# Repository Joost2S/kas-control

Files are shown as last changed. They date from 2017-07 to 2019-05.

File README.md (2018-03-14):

# kas-control
Kas Control is a Raspberry Pi expansion board for watering plants and checking a few more environmental variables
PCB should be correct.
Software is currently not functional. Use v2017 for basic functionality.

Features
--------
- PCB plugs straight into your rPi. rPi is powered through the PCB
- Measuring soil moisture level of up to 7 plants/containers
  - Can pump water to plant/container when moisture level is below threshold so you don't have to!
- Measuring amount of water given per channel and total
- Default 3 temperature sensors are supported by the board. Software supports infinite sensors. Make a simple breakout (connect parallel) board for more sensors.
- Light sensor for ambient light measurement.
- Float switch for use in a water container.
- Outputs:
  - 2 configurable LEDbars.
  - Standard HD44780 16x2 or 20x4 character LCD with driver kindly copied from ADAfruit.
- Network client to set the various setting and get the data.
  - Command-line only. Graph makes a Google graph html file that will open in a new tab in your browser
  - Basic encryption is implemented with openSSL
- Database
  - All sensor data is logged
  - Add a name and plant type to keep track of which plants you've grown
- 5v/12v 4A PSU PCB with INA219 power monitor. PCB files are available, haven't tested it yet.
  - 4 powerLED connectors are available for 350/500/700mA powerLED strips.
  - Power monitoring is available via INA219 ICs
  
Future Features
---------------
- Network
  - Full-fledged GUI for the network client. Probably built on Kivy.
  - rPi camera support so you can watch your plants from all over the world
- Database
  - Adding results such as plant size or harvest amount to each of your plants. Manual input only of course.
- Implement event system

Motivation
----------

I like weed. I like electronics. I like programming. Here's the result :)

Installation/requirements
-------------------------

- I use Arch Linux so only instructions for that. Actual instructions will follow later.
- RPi.GPIO
- SMBus for i2c
- spidev for SPI
- SQlite for database
- Kivy (future)

Contributors
------------

Sorry, no help wanted. This is my pet project and I want it to be just how I like it. Of Course you are welcome to use the code and pcb files as you wish.

License
-------

GNU General Public License v3.0

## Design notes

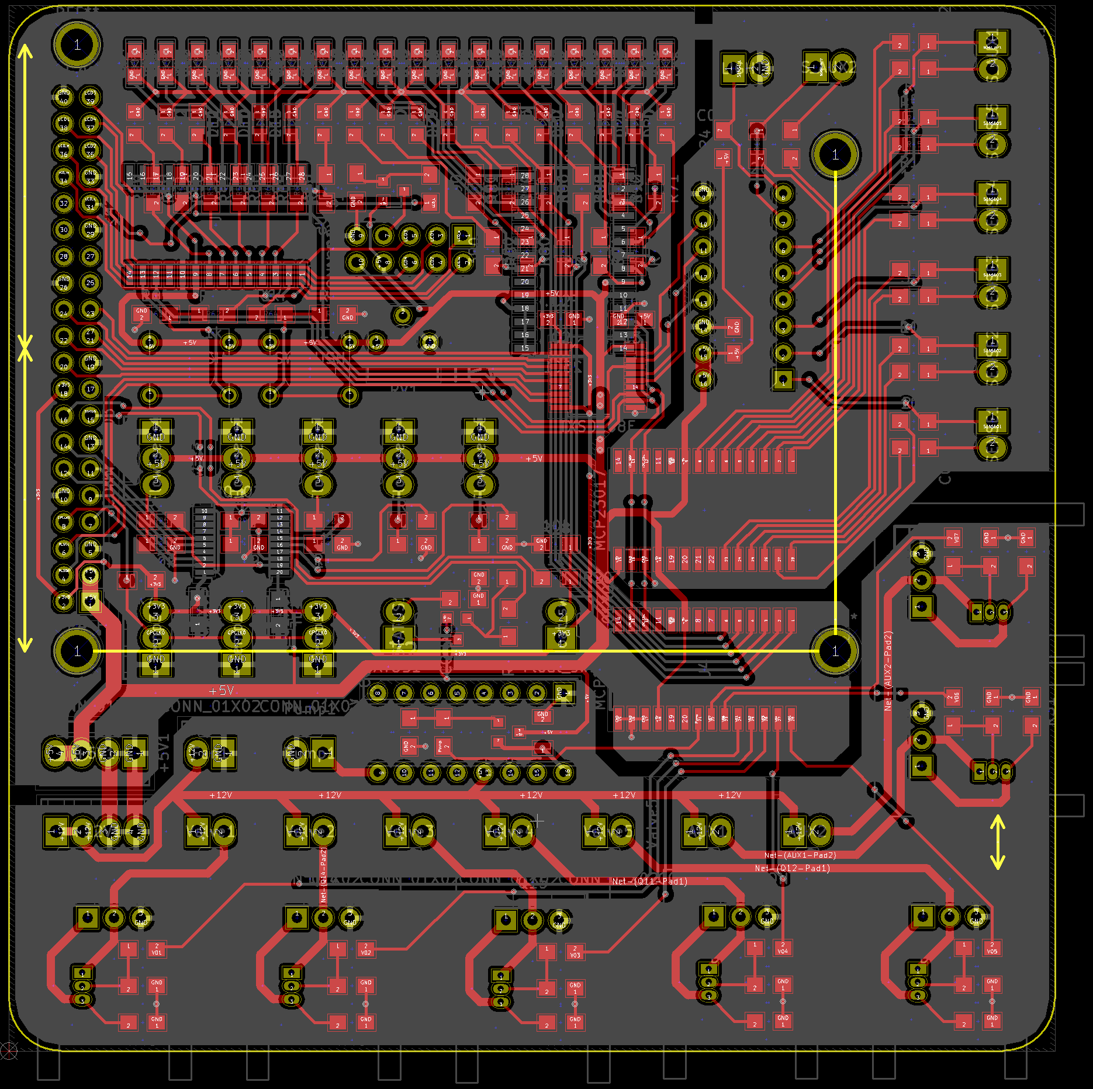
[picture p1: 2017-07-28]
PCB/MainBoard/f.cu.png

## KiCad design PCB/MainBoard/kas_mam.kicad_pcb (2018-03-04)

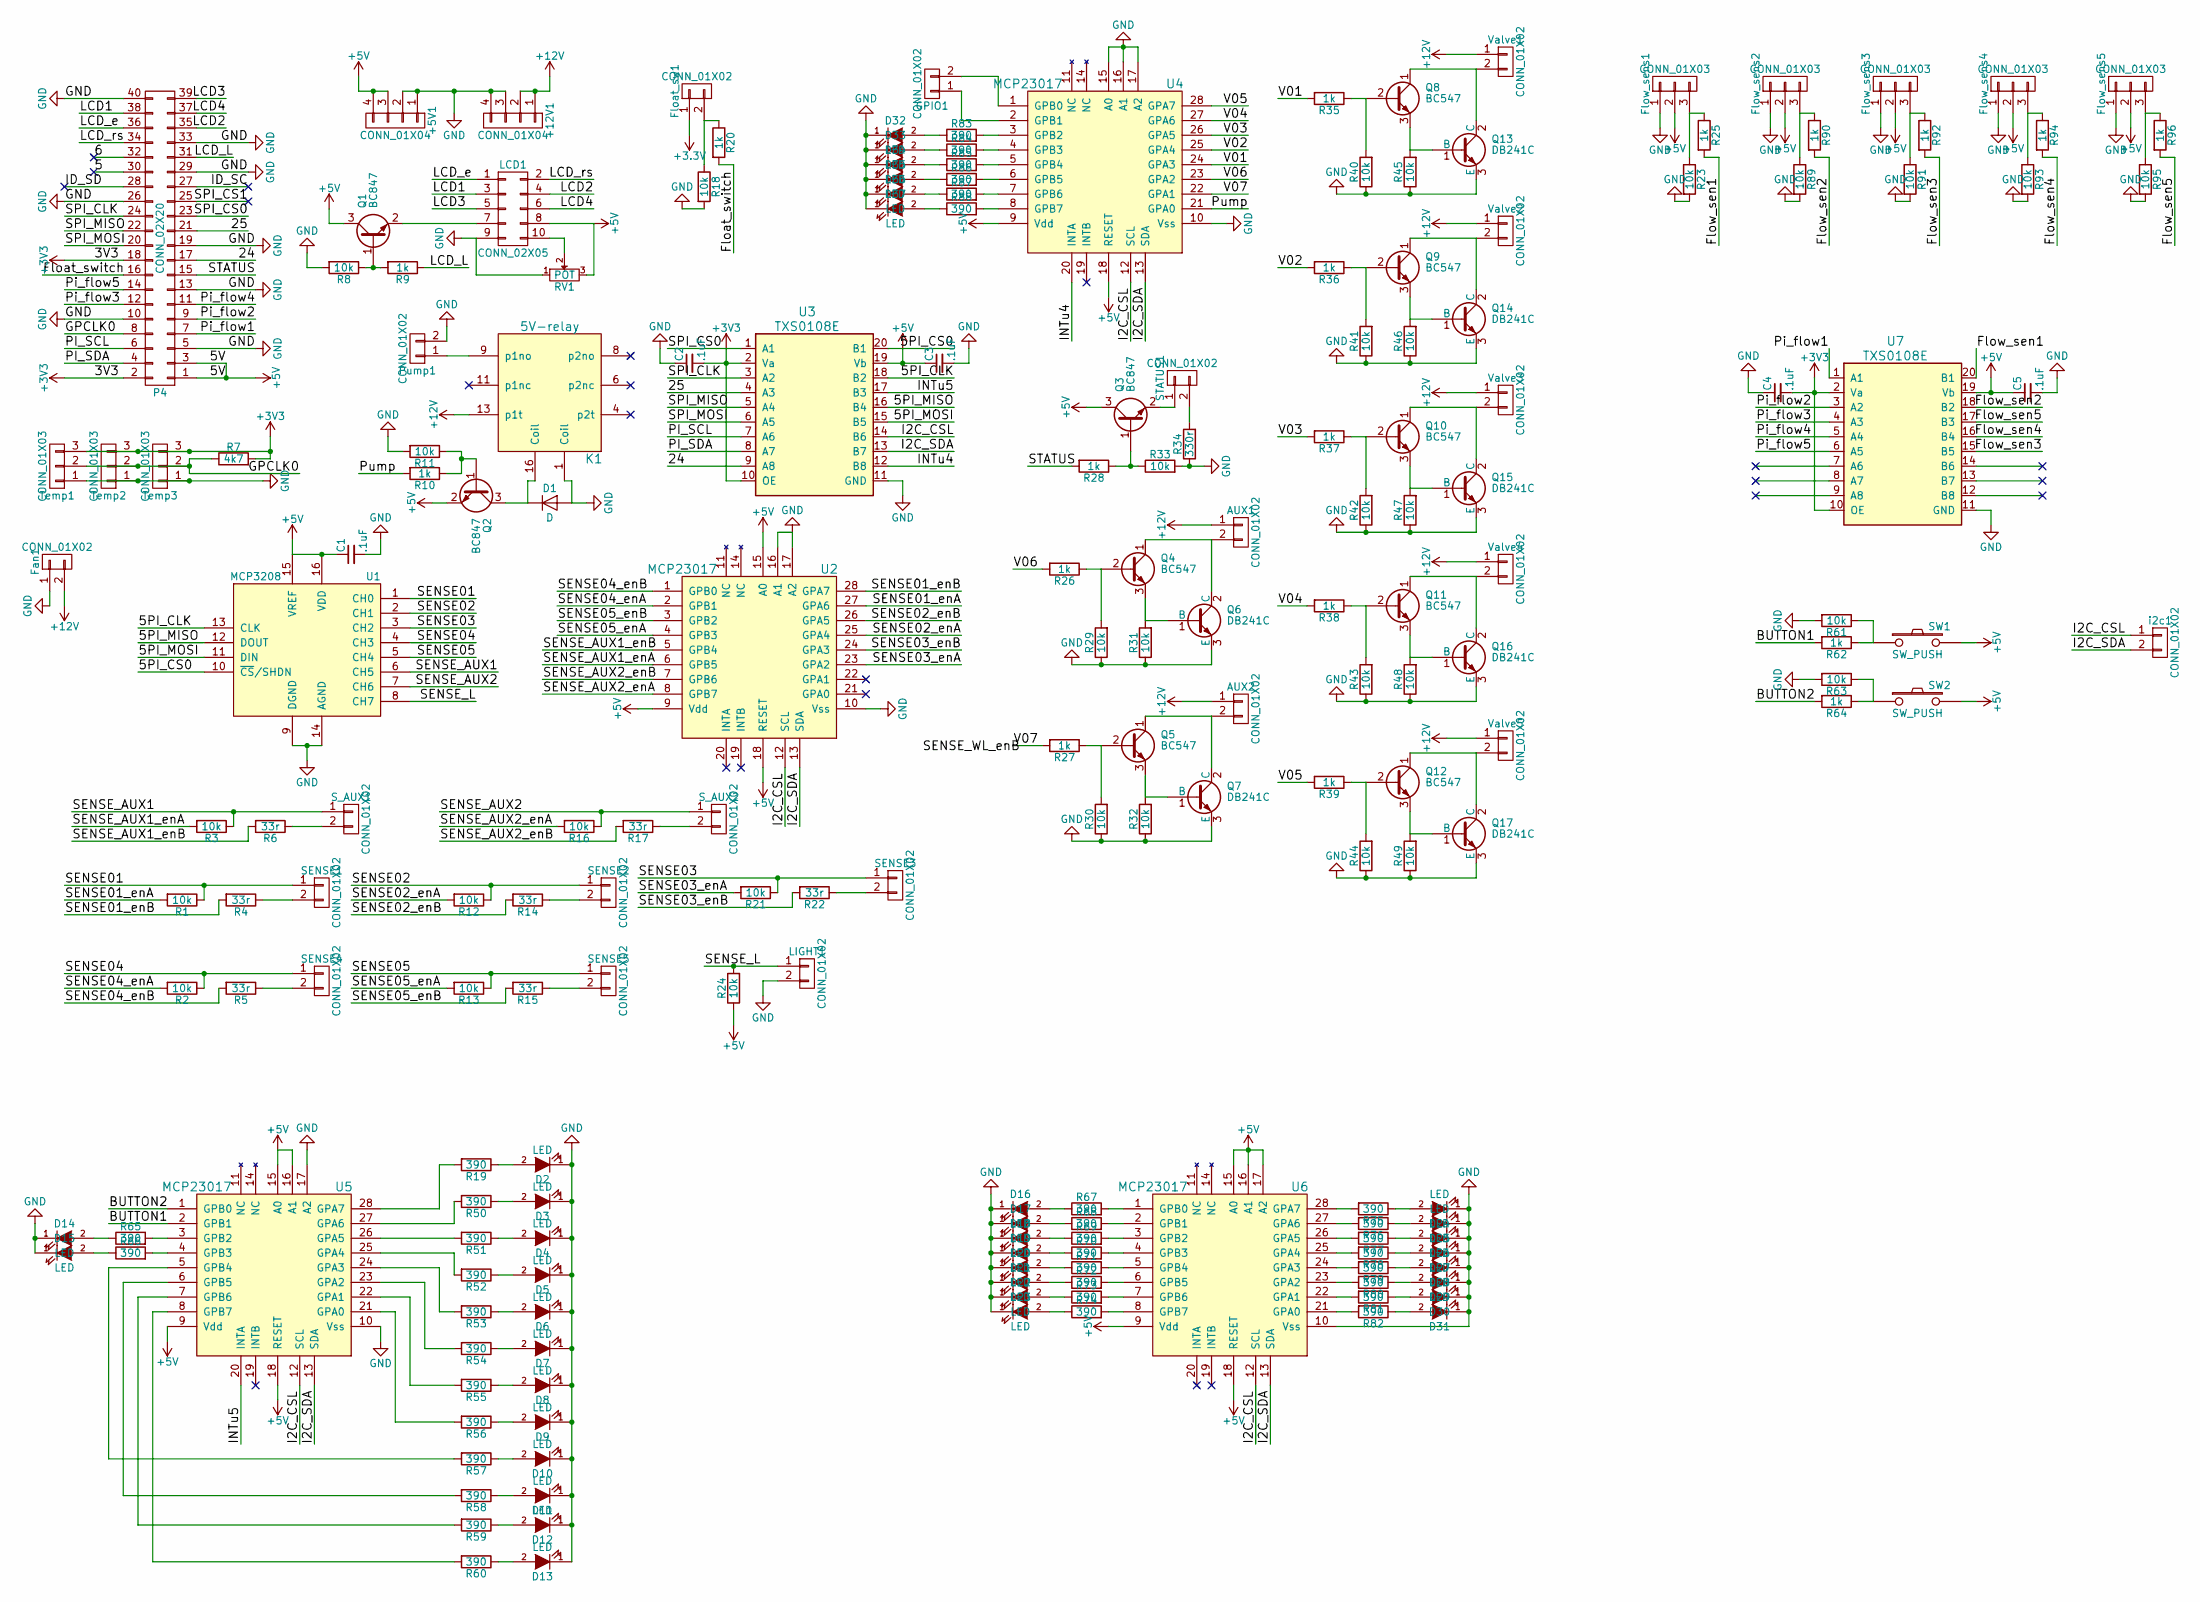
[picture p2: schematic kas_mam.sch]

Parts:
+5V1, +12V1: CONN_01X04; Molex_KK-6410-04_04x2.54mm_Straight
AUX1, AUX2: CONN_01X02; Molex_KK-6410-02_02x2.54mm_Straight
C1, C2, C3, C4, C5: .1uF; C_0805_HandSoldering
D1: D; D_1206
D2, D3, D4, D5, D6, D7, D8, D9, D10, D11, D12, D13, D14, D15, D16, D17, D18, D19, D20, D21, D22, D23, D24, D25, D26, D27, D28, D29, D30, D31, D32, D33, D34, D35, D36, D37: LED; LED_0805
Fan1: CONN_01X02; Molex_KK-6410-02_02x2.54mm_Straight
Float_sw1: CONN_01X02; Molex_KK-6410-02_02x2.54mm_Straight
Flow_sens1, Flow_sens2, Flow_sens3, Flow_sens4, Flow_sens5: CONN_01X03; Molex_KK-6410-03_03x2.54mm_Straight
GPIO1: CONN_01X02; Pin_Header_Straight_1x02_Pitch2.54mm
K1: 5V-relay; DIP-16_W7.62mm_Socket
LCD1: CONN_02X05; Pin_Header_Straight_2x05_Pitch2.54mm
LIGHT1: CONN_01X02; Molex_KK-6410-02_02x2.54mm_Straight
P4: CONN_02X20; Pin_Header_Straight_2x20_Pitch2.54mm
Pump1: CONN_01X02; Molex_KK-6410-02_02x2.54mm_Straight
Q1, Q2, Q3: BC847; SOT-23
Q4, Q5, Q8, Q9, Q10, Q11, Q12: BC547; TO-92_Inline_Narrow_Oval
Q6, Q7, Q13, Q14, Q15, Q16, Q17: DB241C; TO-220_Vertical
R1, R2, R3, R8, R11, R12, R13, R16, R18, R21, R23, R24, R29, R30, R31, R32, R33, R40, R41, R42, R43, R44, R45, R46, R47, R48, R49, R61, R63, R89, R91, R93, R95: 10k; R_0805_HandSoldering
R4, R5, R6, R14, R15, R17, R22: 33r; R_0805_HandSoldering
R7: 4k7; R_0805_HandSoldering
R9, R10, R20, R25, R26, R27, R28, R35, R36, R37, R38, R39, R62, R64, R90, R92, R94, R96: 1k; R_0805_HandSoldering
R19, R50, R51, R52, R53, R54, R55, R56, R57, R58, R59, R60, R65, R66, R67, R68, R69, R70, R71, R72, R73, R74, R75, R76, R77, R78, R79, R80, R81, R82, R83, R84, R85, R86, R87, R88: 390; R_0805_HandSoldering
R34: 330r; R_0805_HandSoldering
RV1: POT; Potentiometer_Trimmer_Vishay_T73YP_Horizontal
SENSE1, SENSE2, SENSE3, SENSE4, SENSE5: CONN_01X02; Molex_KK-6410-02_02x2.54mm_Straight
STATUS1: CONN_01X02; Molex_KK-6410-02_02x2.54mm_Straight
SW1, SW2: SW_PUSH; SW_PUSH_SMALL
S_AUX1, S_AUX2: CONN_01X02; Molex_KK-6410-02_02x2.54mm_Straight
Temp1, Temp2, Temp3: CONN_01X03; Molex_KK-6410-03_03x2.54mm_Straight
U1: MCP3208; DIP-16_W7.62mm_Socket
U2, U4, U5, U6: MCP23017; SOIC-28W_7.5x17.9mm_Pitch1.27mm
U3, U7: TXS0108E; SSOP-20_5.3x7.2mm_Pitch0.65mm
Valve1, Valve2, Valve3, Valve4, Valve5: CONN_01X02; Molex_KK-6410-02_02x2.54mm_Straight
i2c1: CONN_01X02; Molex_KK-6410-02_02x2.54mm_Straight

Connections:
+12V: +12V1.1, +12V1.2, AUX1.1, AUX2.1, Fan1.2, K1.13 (p1t), Valve1.1, Valve2.1, Valve3.1, Valve4.1, Valve5.1
/5PI_CLK: U1.13 (CLK), U3.18 (B2)
/5PI_MISO: U1.12 (DOUT), U3.16 (B4)
/5PI_MOSI: U1.11 (DIN), U3.15 (B5)
/24: P4.17, U3.9 (A8)
/25: P4.21, U3.4 (A3)
/BUTTON1: R62.2, U5.2 (GPB1)
/BUTTON2: R64.2, U5.1 (GPB0)
/Float_switch: P4.16, R20.2
/Flow_sen1: R25.2, U7.20 (B1)
/Flow_sen2: R90.2, U7.18 (B2)
/Flow_sen3: R92.2, U7.15 (B5)
/Flow_sen4: R94.2, U7.16 (B4)
/Flow_sen5: R96.2, U7.17 (B3)
/GPCLK0: P4.8, R7.1, Temp1.2, Temp2.2, Temp3.2
/I2C_CSL: U2.12 (SCL), U3.14 (B6), U4.12 (SCL), U5.12 (SCL), U6.12 (SCL), i2c1.1
/I2C_SDA: U2.13 (SDA), U3.13 (B7), U4.13 (SDA), U5.13 (SDA), U6.13 (SDA), i2c1.2
/INTu4: U3.12 (B8), U4.20 (INTA)
/INTu5: U3.17 (B3), U5.20 (INTA)
/LCD1: LCD1.3, P4.38
/LCD2: LCD1.4, P4.35
/LCD3: LCD1.5, P4.39
/LCD4: LCD1.6, P4.37
/LCD_L: P4.31, R9.1
/LCD_e: LCD1.1, P4.36
/LCD_rs: LCD1.2, P4.34
/PI_SCL: P4.6, U3.7 (A6)
/PI_SDA: P4.4, U3.8 (A7)
/Pi_flow1: P4.7, U7.1 (A1)
/Pi_flow2: P4.9, U7.3 (A2)
/Pi_flow3: P4.12, U7.4 (A3)
/Pi_flow4: P4.11, U7.5 (A4)
/Pi_flow5: P4.14, U7.6 (A5)
/Pump: R10.2, U4.21 (GPA0)
/SENSE01: R1.1, SENSE1.1, U1.1 (CH0)
/SENSE01_enA: R1.2, U2.27 (GPA6)
/SENSE01_enB: R4.2, U2.28 (GPA7)
/SENSE02: R12.1, SENSE2.1, U1.2 (CH1)
/SENSE02_enA: R12.2, U2.25 (GPA4)
/SENSE02_enB: R14.2, U2.26 (GPA5)
/SENSE03: R21.1, SENSE3.1, U1.3 (CH2)
/SENSE03_enA: R21.2, U2.23 (GPA2)
/SENSE03_enB: R22.2, U2.24 (GPA3)
/SENSE04: R2.1, SENSE4.1, U1.4 (CH3)
/SENSE04_enA: R2.2, U2.2 (GPB1)
/SENSE04_enB: R5.2, U2.1 (GPB0)
/SENSE05: R13.1, SENSE5.1, U1.5 (CH4)
/SENSE05_enA: R13.2, U2.4 (GPB3)
/SENSE05_enB: R15.2, U2.3 (GPB2)
/SENSE_AUX1: R3.1, S_AUX1.1, U1.6 (CH5)
/SENSE_AUX1_enA: R3.2, U2.6 (GPB5)
/SENSE_AUX1_enB: R6.2, U2.5 (GPB4)
/SENSE_AUX2: R16.1, S_AUX2.1, U1.7 (CH6)
/SENSE_AUX2_enA: R16.2, U2.8 (GPB7)
/SENSE_AUX2_enB: R17.2, U2.7 (GPB6)
/SENSE_L: LIGHT1.1, R24.2, U1.8 (CH7)
/SPI_CLK: P4.24, U3.3 (A2)
/SPI_MISO: P4.22, U3.5 (A4)
/SPI_MOSI: P4.20, U3.6 (A5)
/STATUS: P4.15, R28.2
/V01: R35.2, U4.24 (GPA3)
/V02: R36.2, U4.25 (GPA4)
/V03: R37.2, U4.26 (GPA5)
/V04: R38.2, U4.27 (GPA6)
/V05: R39.2, U4.28 (GPA7)
/V06: R26.2, U4.23 (GPA2)
/V07: R27.2, U4.22 (GPA1)
GND: +5V1.1, +5V1.2, +12V1.3, +12V1.4, C1.2, C2.1, C3.2, C4.1, C5.2, D1.2 (A), D2.1 (K), D3.1 (K), D4.1 (K), D5.1 (K), D6.1 (K), D7.1 (K), D8.1 (K), D9.1 (K), D10.1 (K), D11.1 (K), D12.1 (K), D13.1 (K), D14.1 (K), D15.1 (K), D16.1 (K), D17.1 (K), D18.1 (K), D19.1 (K), D20.1 (K), D21.1 (K), D22.1 (K), D23.1 (K), D24.1 (K), D25.1 (K), D26.1 (K), D27.1 (K), D28.1 (K), D29.1 (K), D30.1 (K), D31.1 (K), D32.1 (K), D33.1 (K), D34.1 (K), D35.1 (K), D36.1 (K), D37.1 (K), Fan1.1, Flow_sens1.1, Flow_sens2.1, Flow_sens3.1, Flow_sens4.1, Flow_sens5.1, K1.1 (Coil), LCD1.9, LIGHT1.2, P4.5, P4.10, P4.13, P4.19, P4.26, P4.29, P4.33, P4.40, Pump1.2, Q6.3 (E), Q7.3 (E), Q13.3 (E), Q14.3 (E), Q15.3 (E), Q16.3 (E), Q17.3 (E), R8.2, R11.2, R18.2, R23.2, R29.1, R30.1, R31.1, R32.1, R33.2, R34.1, R40.1, R41.1, R42.1, R43.1, R44.1, R45.1, R46.1, R47.1, R48.1, R49.1, R61.2, R63.2, R89.2, R91.2, R93.2, R95.2, RV1.1, Temp1.1, Temp2.1, Temp3.1, U1.9 (DGND), U1.14 (AGND), U2.10 (Vss), U2.16 (A1), U2.17 (A2), U3.11 (GND), U4.10 (Vss), U4.15 (A0), U4.16 (A1), U4.17 (A2), U5.10 (Vss), U5.17 (A2), U6.10 (Vss), U7.11 (GND)
unnamed: AUX1.2, Q4.1 (C), Q6.2 (C)
unnamed: AUX2.2, Q5.1 (C), Q7.2 (C)
unnamed: D1.1 (K), K1.16 (Coil), Q2.3 (C)
unnamed: D2.2 (A), R19.1
unnamed: D3.2 (A), R50.1
unnamed: D4.2 (A), R51.1
unnamed: D5.2 (A), R52.1
unnamed: D6.2 (A), R53.1
unnamed: D7.2 (A), R54.1
unnamed: D8.2 (A), R55.1
unnamed: D9.2 (A), R56.1
unnamed: D10.2 (A), R57.1
unnamed: D11.2 (A), R58.1
unnamed: D12.2 (A), R59.1
unnamed: D13.2 (A), R60.1
unnamed: D14.2 (A), R65.1
unnamed: D15.2 (A), R66.1
unnamed: D16.2 (A), R67.1
unnamed: D17.2 (A), R68.1
unnamed: D18.2 (A), R69.1
unnamed: D19.2 (A), R70.1
unnamed: D20.2 (A), R71.1
unnamed: D21.2 (A), R72.1
unnamed: D22.2 (A), R73.1
unnamed: D23.2 (A), R74.1
unnamed: D24.2 (A), R75.1
unnamed: D25.2 (A), R76.1
unnamed: D26.2 (A), R77.1
unnamed: D27.2 (A), R78.1
unnamed: D28.2 (A), R79.1
unnamed: D29.2 (A), R80.1
unnamed: D30.2 (A), R81.1
unnamed: D31.2 (A), R82.1
unnamed: D32.2 (A), R83.1
unnamed: D33.2 (A), R84.1
unnamed: D34.2 (A), R85.1
unnamed: D35.2 (A), R86.1
unnamed: D36.2 (A), R87.1
unnamed: D37.2 (A), R88.1
unnamed: Float_sw1.2, R18.1, R20.1
unnamed: Flow_sens1.3, R23.1, R25.1
unnamed: Flow_sens2.3, R89.1, R90.1
unnamed: Flow_sens3.3, R91.1, R92.1
unnamed: Flow_sens4.3, R93.1, R94.1
unnamed: Flow_sens5.3, R95.1, R96.1
unnamed: GPIO1.1, U4.2 (GPB1)
unnamed: GPIO1.2, U4.1 (GPB0)
unnamed: K1.9 (p1no), Pump1.1
unnamed: LCD1.7, Q1.2 (E)
unnamed: LCD1.10, RV1.2
unnamed: Q1.1 (B), R8.1, R9.2
unnamed: Q2.1 (B), R10.1, R11.1
unnamed: Q3.1 (B), R28.1, R33.1
unnamed: Q3.2 (E), STATUS1.1
unnamed: Q4.2 (B), R26.1, R29.2
unnamed: Q4.3 (E), Q6.1 (B), R31.2
unnamed: Q5.2 (B), R27.1, R30.2
unnamed: Q5.3 (E), Q7.1 (B), R32.2
unnamed: Q8.2 (B), R35.1, R40.2
unnamed: Q9.2 (B), R36.1, R41.2
unnamed: Q10.1 (C), Q15.2 (C), Valve3.2
unnamed: Q10.2 (B), R37.1, R42.2
unnamed: Q10.3 (E), Q15.1 (B), R47.2
unnamed: Q11.1 (C), Q16.2 (C), Valve4.2
unnamed: Q11.2 (B), R38.1, R43.2
unnamed: Q11.3 (E), Q16.1 (B), R48.2
unnamed: Q12.1 (C), Q17.2 (C), Valve5.2
unnamed: Q12.2 (B), R39.1, R44.2
unnamed: Q12.3 (E), Q17.1 (B), R49.2
unnamed: Q8.3 (E), Q13.1 (B), R45.2
unnamed: Q8.1 (C), Q13.2 (C), Valve1.2
unnamed: Q9.3 (E), Q14.1 (B), R46.2
unnamed: Q9.1 (C), Q14.2 (C), Valve2.2
unnamed: R4.1, SENSE1.2
unnamed: R5.1, SENSE4.2
unnamed: R6.1, S_AUX1.2
unnamed: R14.1, SENSE2.2
unnamed: R15.1, SENSE5.2
unnamed: R17.1, S_AUX2.2
unnamed: R19.2, U5.28 (GPA7)
unnamed: R22.1, SENSE3.2
unnamed: R34.2, STATUS1.2
unnamed: R50.2, U5.27 (GPA6)
unnamed: R51.2, U5.26 (GPA5)
unnamed: R52.2, U5.25 (GPA4)
unnamed: R53.2, U5.24 (GPA3)
unnamed: R54.2, U5.23 (GPA2)
unnamed: R55.2, U5.22 (GPA1)
unnamed: R56.2, U5.21 (GPA0)
unnamed: R57.2, U5.5 (GPB4)
unnamed: R58.2, U5.6 (GPB5)
unnamed: R59.2, U5.7 (GPB6)
unnamed: R60.2, U5.8 (GPB7)
unnamed: R61.1, R62.1, SW1.1
unnamed: R63.1, R64.1, SW2.1
unnamed: R65.2, U5.3 (GPB2)
unnamed: R66.2, U5.4 (GPB3)
unnamed: R67.2, U6.1 (GPB0)
unnamed: R68.2, U6.2 (GPB1)
unnamed: R69.2, U6.3 (GPB2)
unnamed: R70.2, U6.4 (GPB3)
unnamed: R71.2, U6.5 (GPB4)
unnamed: R72.2, U6.6 (GPB5)
unnamed: R73.2, U6.7 (GPB6)
unnamed: R74.2, U6.8 (GPB7)
unnamed: R75.2, U6.28 (GPA7)
unnamed: R76.2, U6.27 (GPA6)
unnamed: R77.2, U6.26 (GPA5)
unnamed: R78.2, U6.25 (GPA4)
unnamed: R79.2, U6.24 (GPA3)
unnamed: R80.2, U6.23 (GPA2)
unnamed: R81.2, U6.22 (GPA1)
unnamed: R82.2, U6.21 (GPA0)
unnamed: R83.2, U4.3 (GPB2)
unnamed: R84.2, U4.4 (GPB3)
unnamed: R85.2, U4.5 (GPB4)
unnamed: R86.2, U4.6 (GPB5)
unnamed: R87.2, U4.7 (GPB6)
unnamed: R88.2, U4.8 (GPB7)

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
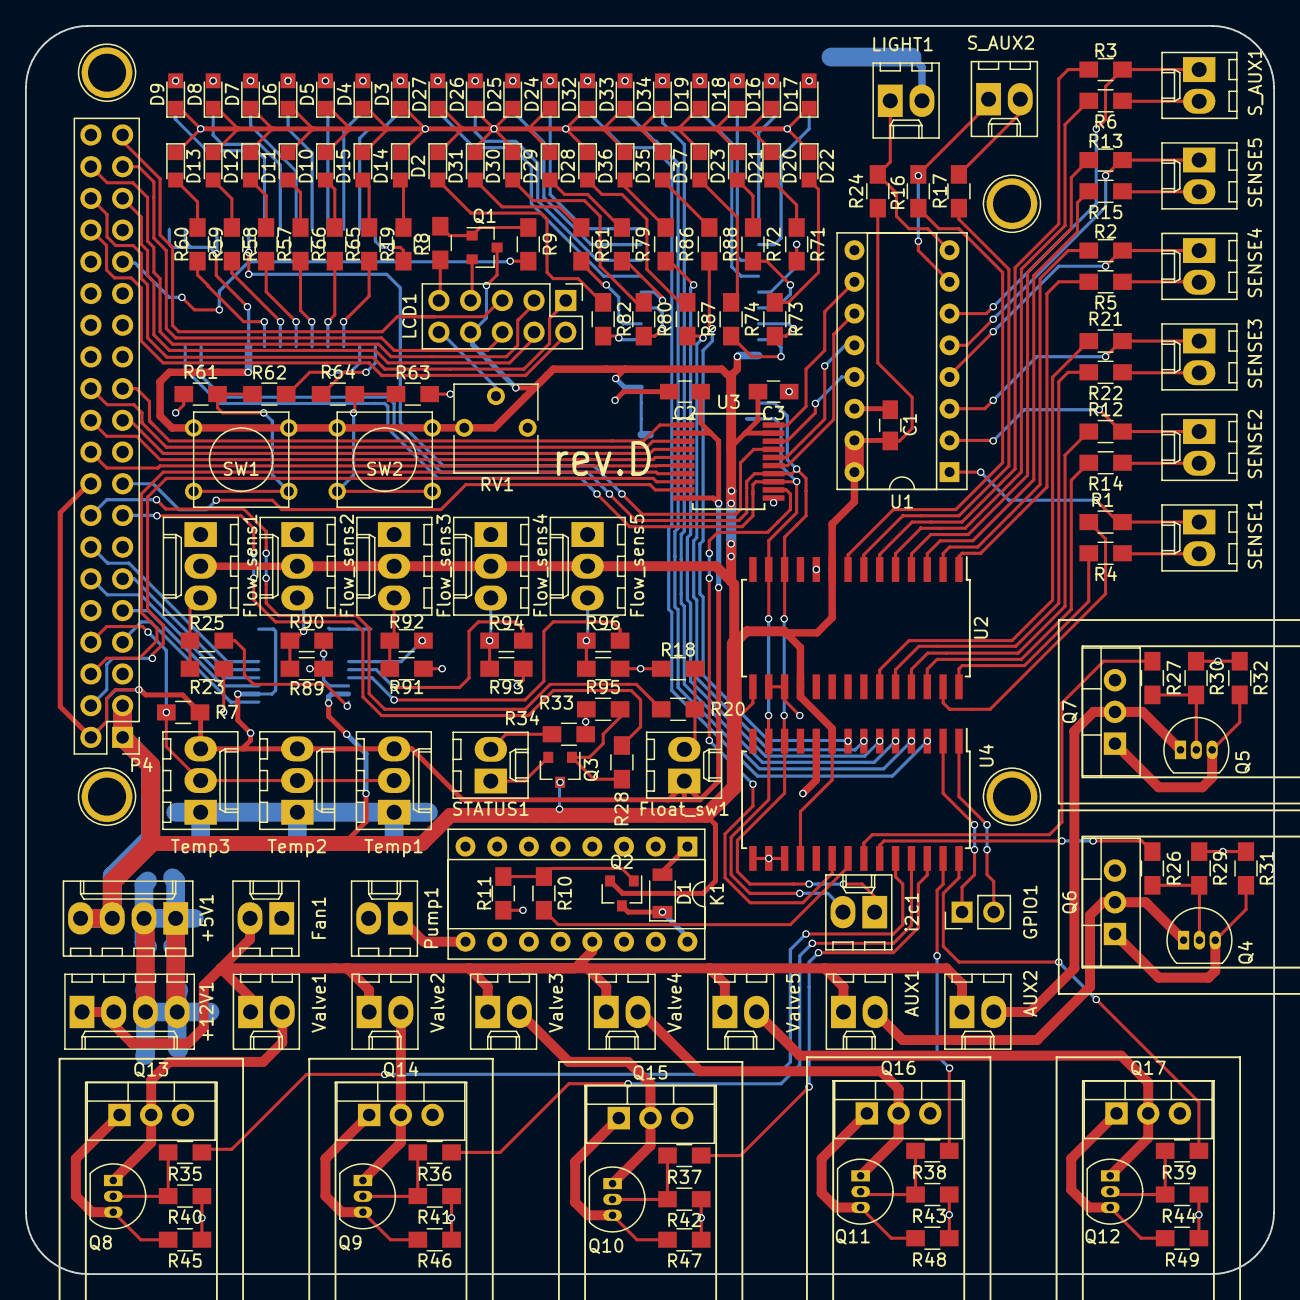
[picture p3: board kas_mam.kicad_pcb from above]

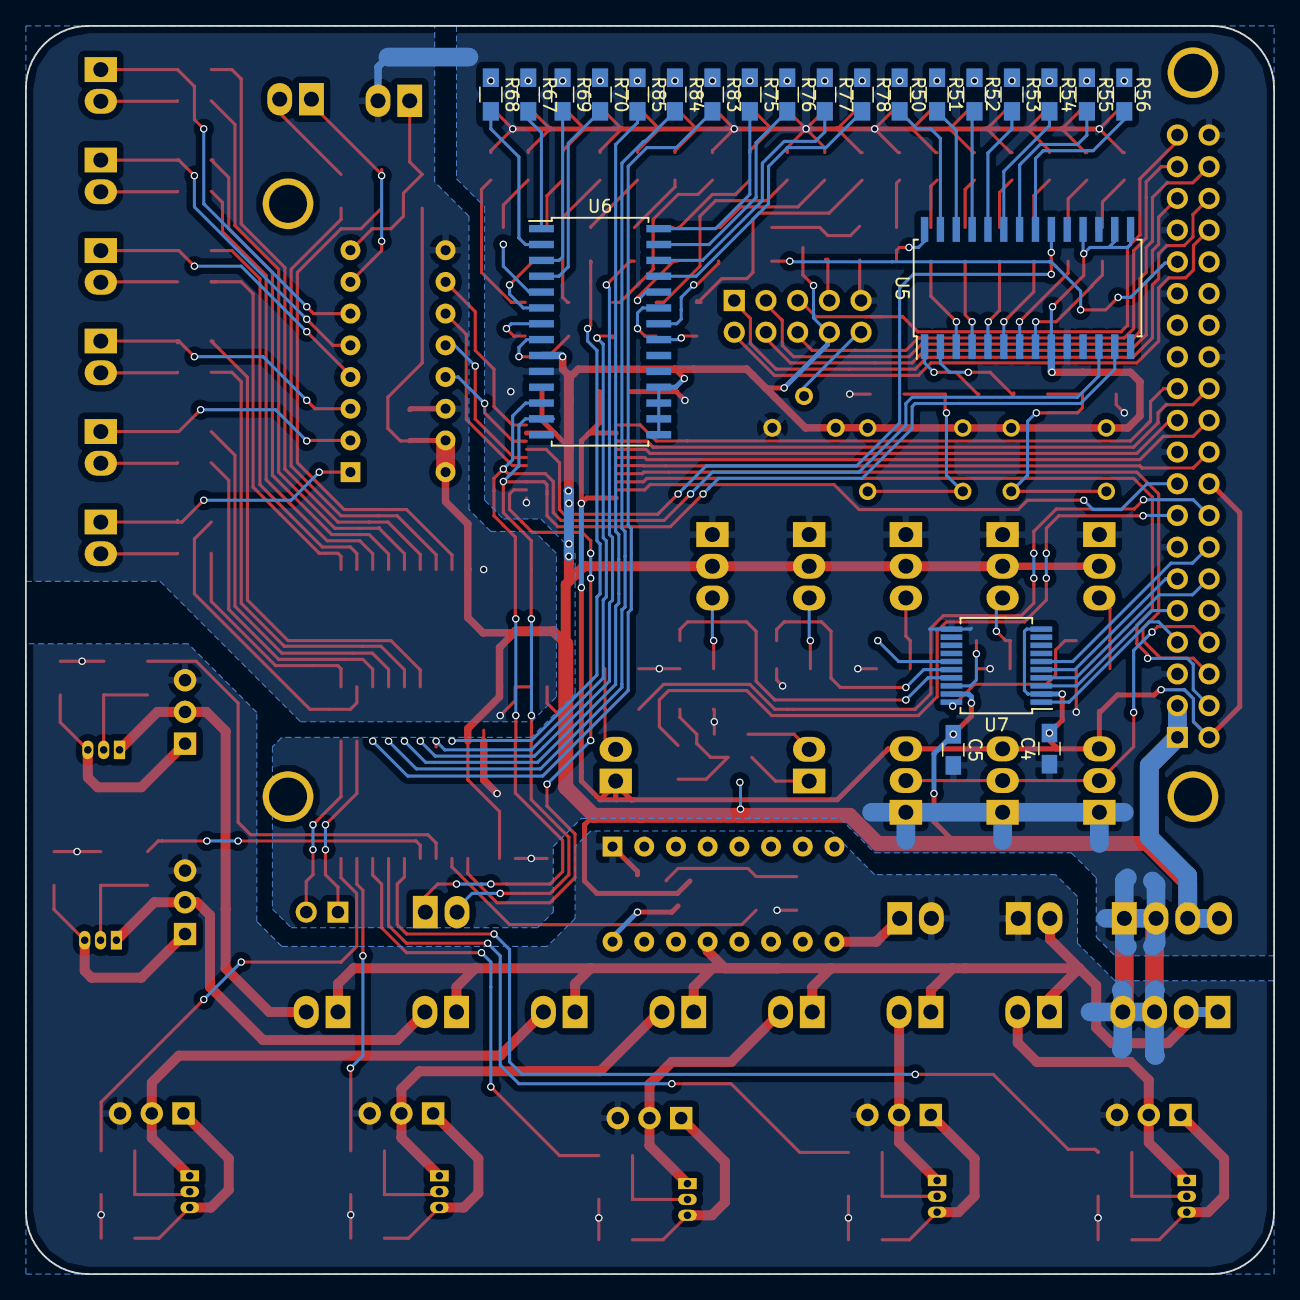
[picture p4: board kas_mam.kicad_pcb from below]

Board: 2 copper layers, 100.0 x 100.0 mm, 199 parts (23 on the bottom side), 191 nets.

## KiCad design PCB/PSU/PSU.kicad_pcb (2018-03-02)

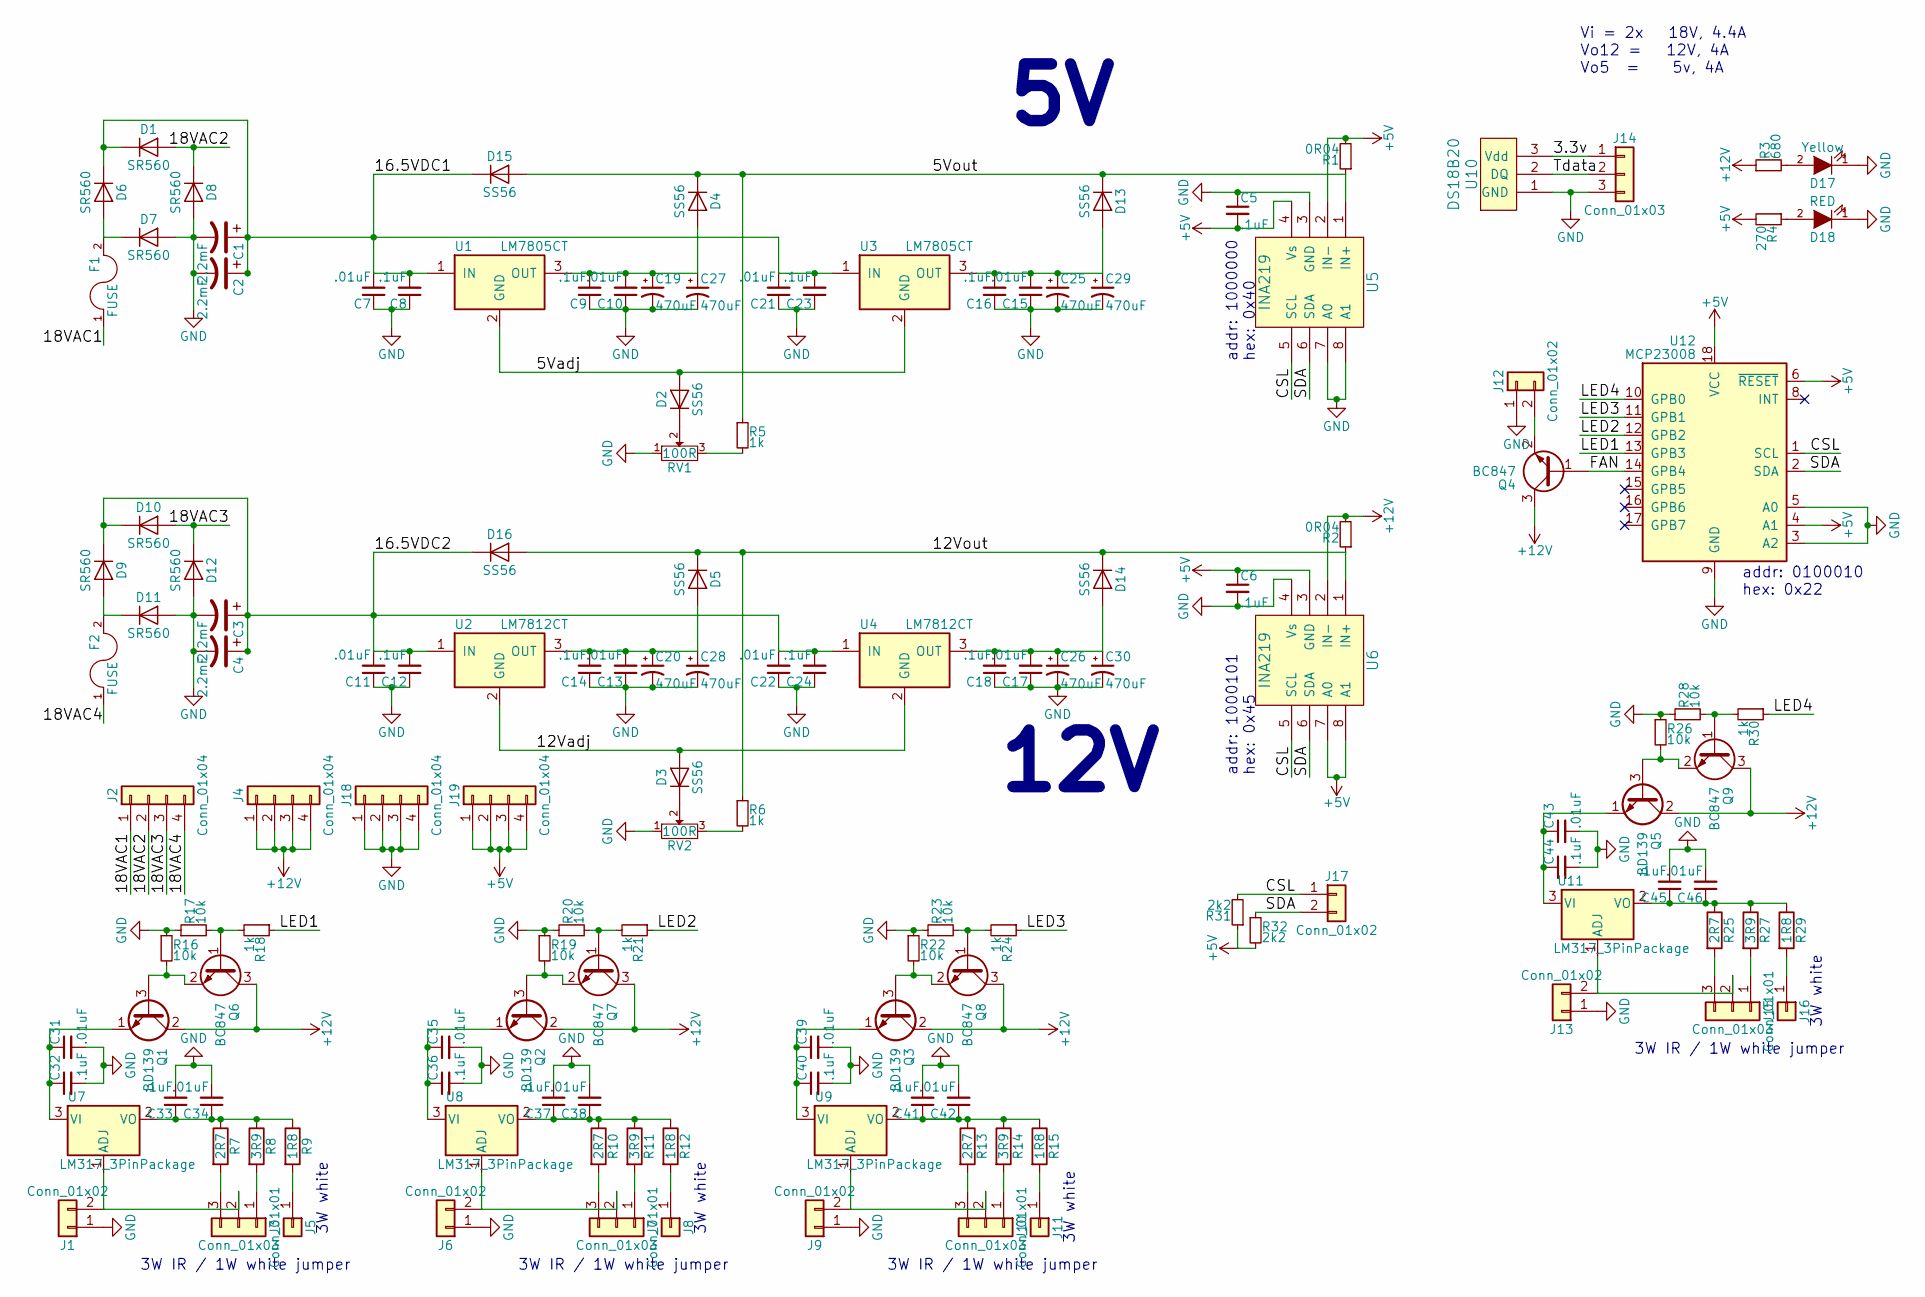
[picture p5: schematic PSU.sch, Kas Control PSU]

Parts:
C1, C2, C3, C4: 2.2mF; CP_Radial_D16.0mm_P7.50mm
C5, C6, C8, C9, C12, C14, C16, C18, C23, C24, C32, C33, C36, C37, C40, C41, C44, C45: .1uF; C_0805_HandSoldering
C7, C10, C11, C13, C15, C17, C21, C22, C31, C34, C35, C38, C39, C42, C43, C46: .01uF; C_0805_HandSoldering
C19, C20, C25, C26, C27, C28, C29, C30: 470uF; CP_Radial_D8.0mm_P3.50mm
D1, D6, D7, D9, D10, D11, D12: SR560; D_DO-201AD_P15.24mm_Horizontal
D2, D3, D4, D5, D13, D14, D15, D16: SS56; D_SMA_Handsoldering
D8: SR560; D_DO-201_P15.24mm_Horizontal
D17: Yellow; LED_D5.0mm
D18: RED; LED_D5.0mm
F1, F2: FUSE; Fuseholder5x20_horiz_SemiClosed_Casing10x25mm
J1, J6, J9, J13, J17: Conn_01x02; Molex_KK-6410-02_02x2.54mm_Straight
J2, J4: Conn_01x04; TerminalBlock_Philmore_TB13x_04x5mm_Straight
J3, J7, J10, J15: Conn_01x03; Pin_Header_Straight_1x03_Pitch2.54mm
J5, J8, J11, J16: Conn_01x01; Pin_Header_Straight_1x01_Pitch2.54mm
J12: Conn_01x02; Molex_KK-6410-03_03x2.54mm_Straight
J14: Conn_01x03; Molex_KK-6410-03_03x2.54mm_Straight
J18, J19: Conn_01x04; TerminalBlock_bornier-4_P5.08mm
Q1, Q2, Q3, Q5: BD139; TO-126_Vertical
Q4, Q6, Q7, Q8, Q9: BC847; SOT-23
R1, R2: 0R04; R_2512_HandSoldering
R3: 680; R_Axial_DIN0207_L6.3mm_D2.5mm_P7.62mm_Horizontal
R4: 270; R_Axial_DIN0207_L6.3mm_D2.5mm_P7.62mm_Horizontal
R5, R6, R18, R21, R24, R30: 1k; R_0805_HandSoldering
R7, R10, R13, R25: 2R7; R_Axial_DIN0309_L9.0mm_D3.2mm_P2.54mm_Vertical
R8, R11, R14, R27: 3R9; R_Axial_DIN0309_L9.0mm_D3.2mm_P2.54mm_Vertical
R9, R12, R15, R29: 1R8; R_Axial_DIN0309_L9.0mm_D3.2mm_P2.54mm_Vertical
R16, R17, R19, R20, R22, R23, R26, R28: 10k; R_0805_HandSoldering
R31, R32: 2k2; R_0805_HandSoldering
RV1, RV2: 100R; Potentiometer_Trimmer_Vishay_T73YP_Horizontal
U1, U3: LM7805CT; TO-220_Vertical
U2, U4: LM7812CT; TO-220_Vertical
U5, U6: INA219; SOT-23-8
U7, U8, U9, U11: LM317_3PinPackage; TO-220_Vertical
U10: DS18B20; TO-92_Inline_Wide
U12: MCP23008; SOIC-18W_7.5x11.6mm_Pitch1.27mm

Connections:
+5V: C5.2, C6.1, J19.1, J19.2, J19.3, J19.4, R1.2, R4.2, R31.1, R32.2, U5.2 (IN-), U5.4 (Vs), U6.3 (GND), U6.7 (A0), U6.8 (A1), U12.4 (A1), U12.6 (~RESET), U12.18 (VCC)
+12V: J4.1, J4.2, J4.3, J4.4, Q1.2 (C), Q2.2 (C), Q3.2 (C), Q4.3 (C), Q5.2 (C), Q6.3 (C), Q7.3 (C), Q8.3 (C), Q9.3 (C), R2.2, R3.1, U6.2 (IN-)
/3.3v: J14.1, U10.3 (Vdd)
/5Vadj: D2.2 (A), U1.2 (GND), U3.2 (GND)
/5Vout: D4.1 (K), D13.1 (K), D15.2 (A), R1.1, R5.1, U5.1 (IN+)
/12Vadj: D3.2 (A), U2.2 (GND), U4.2 (GND)
/12Vout: D5.1 (K), D14.1 (K), D16.2 (A), R2.1, R6.1, U6.1 (IN+)
/16.5VDC1: C1.1, C2.1, C7.2, C8.2, C21.2, C23.2, D1.1 (K), D6.1 (K), D15.1 (K), U1.1 (IN), U3.1 (IN)
/16.5VDC2: C3.1, C4.1, C11.2, C12.2, C22.2, C24.2, D9.1 (K), D10.1 (K), D16.1 (K), U2.1 (IN), U4.1 (IN)
/18VAC1: F1.1, J2.1
/18VAC2: D1.2 (A), D8.1 (K), J2.2
/18VAC3: D10.2 (A), D12.1 (K), J2.3
/18VAC4: F2.1, J2.4
/CSL: J17.1, R31.2, U5.5 (SCL), U6.5 (SCL), U12.1 (SCL)
/FAN: Q4.1 (B), U12.14 (GPB4)
/LED1: R18.1, U12.13 (GPB3)
/LED2: R21.1, U12.12 (GPB2)
/LED3: R24.1, U12.11 (GPB1)
/LED4: R30.1, U12.10 (GPB0)
/SDA: J17.2, R32.1, U5.6 (SDA), U6.6 (SDA), U12.2 (SDA)
/Tdata: J14.2, U10.2 (DQ)
GND: C1.2, C2.2, C3.2, C4.2, C5.1, C6.2, C7.1, C8.1, C9.1, C10.1, C11.1, C12.1, C13.1, C14.1, C15.1, C16.1, C17.1, C18.1, C19.2, C20.2, C21.1, C22.1, C23.1, C24.1, C25.2, C26.2, C27.2, C28.2, C29.2, C30.2, C31.2, C32.2, C33.2, C34.2, C35.2, C36.2, C37.2, C38.2, C39.2, C40.2, C41.2, C42.2, C43.2, C44.2, C45.2, C46.2, D7.2 (A), D8.2 (A), D11.2 (A), D12.2 (A), D17.1 (K), D18.1 (K), J1.1, J6.1, J9.1, J12.1, J13.1, J14.3, J18.1, J18.2, J18.3, J18.4, R16.1, R17.1, R19.1, R20.1, R22.1, R23.1, R26.1, R28.1, RV1.1, RV2.1, U5.3 (GND), U5.7 (A0), U5.8 (A1), U6.4 (Vs), U10.1 (GND), U12.3 (A2), U12.5 (A0), U12.9 (GND)
unnamed: C9.2, C10.2, C19.1, C27.1, D4.2 (A), U1.3 (OUT)
unnamed: C13.2, C14.2, C20.1, C28.1, D5.2 (A), U2.3 (OUT)
unnamed: C15.2, C16.2, C25.1, C29.1, D13.2 (A), U3.3 (OUT)
unnamed: C17.2, C18.2, C26.1, C30.1, D14.2 (A), U4.3 (OUT)
unnamed: C31.1, C32.1, Q1.1 (E), U7.3 (VI)
unnamed: C33.1, C34.1, R7.1, R8.1, R9.1, U7.2 (VO)
unnamed: C35.1, C36.1, Q2.1 (E), U8.3 (VI)
unnamed: C37.1, C38.1, R10.1, R11.1, R12.1, U8.2 (VO)
unnamed: C39.1, C40.1, Q3.1 (E), U9.3 (VI)
unnamed: C41.1, C42.1, R13.1, R14.1, R15.1, U9.2 (VO)
unnamed: C43.1, C44.1, Q5.1 (E), U11.3 (VI)
unnamed: C45.1, C46.1, R25.1, R27.1, R29.1, U11.2 (VO)
unnamed: D2.1 (K), RV1.2
unnamed: D3.1 (K), RV2.2
unnamed: D6.2 (A), D7.1 (K), F1.2
unnamed: D9.2 (A), D11.1 (K), F2.2
unnamed: D17.2 (A), R3.2
unnamed: D18.2 (A), R4.1
unnamed: J1.2, J3.2, U7.1 (ADJ)
unnamed: J3.1, R8.2
unnamed: J3.3, R7.2
unnamed: J5.1, R9.2
unnamed: J6.2, J7.2, U8.1 (ADJ)
unnamed: J7.1, R11.2
unnamed: J7.3, R10.2
unnamed: J8.1, R12.2
unnamed: J10.1, R14.2
unnamed: J9.2, J10.2, U9.1 (ADJ)
unnamed: J10.3, R13.2
unnamed: J11.1, R15.2
unnamed: J12.2, Q4.2 (E)
unnamed: J13.2, J15.2, U11.1 (ADJ)
unnamed: J15.1, R27.2
unnamed: J15.3, R25.2
unnamed: J16.1, R29.2
unnamed: Q1.3 (B), Q6.2 (E), R16.2
unnamed: Q2.3 (B), Q7.2 (E), R19.2
unnamed: Q3.3 (B), Q8.2 (E), R22.2
unnamed: Q5.3 (B), Q9.2 (E), R26.2
unnamed: Q6.1 (B), R17.2, R18.2
unnamed: Q7.1 (B), R20.2, R21.2
unnamed: Q8.1 (B), R23.2, R24.2
unnamed: Q9.1 (B), R28.2, R30.2
unnamed: R5.2, RV1.3
unnamed: R6.2, RV2.3

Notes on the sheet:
Vi = 2x 18V, 4.4A Vo12 = 12V, 4A Vo5 = 5v, 4A
12V
3W IR / 1W white jumper
3W white
addr: 1000101 hex: 0x45
addr: 1000000 hex: 0x40
addr: 0100010 hex: 0x22

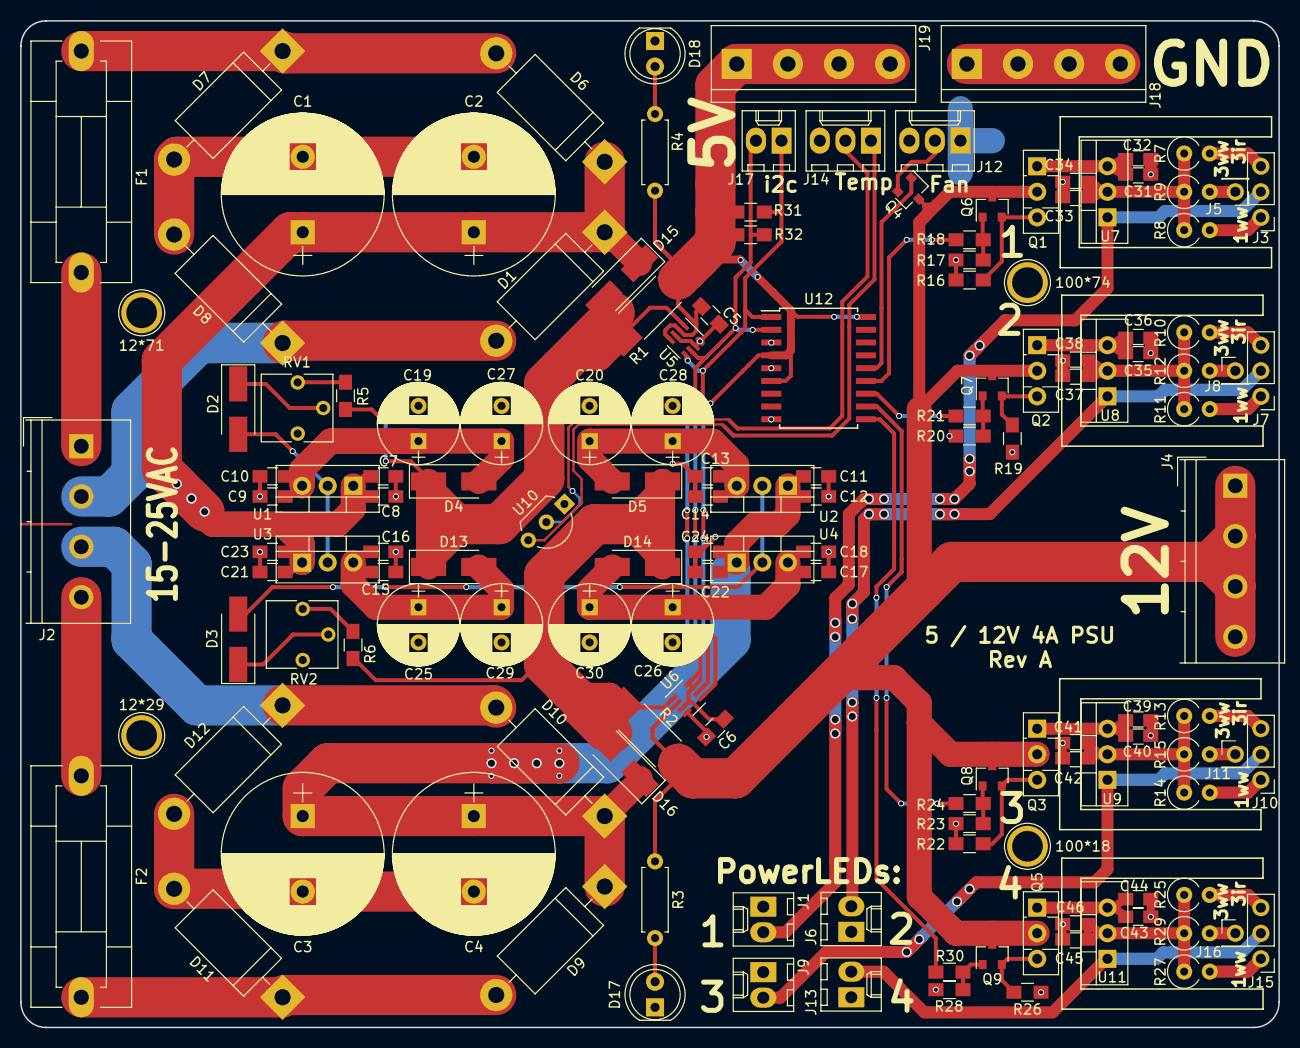
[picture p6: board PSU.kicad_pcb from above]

Board: 2 copper layers, 125.0 x 100.0 mm, 144 parts (0 on the bottom side), 67 nets.

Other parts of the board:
12*29, 12*71, 100*18, 100*74: 1pin

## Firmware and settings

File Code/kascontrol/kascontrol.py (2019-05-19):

#!/usr/bin/python3

# Author: J. Saarloos
# v0.08.02	19-05-2019


import logging

from Code.kascontrol.core.database import Database
from Code.kascontrol.core.db.datalog import DatalogThread
from Code.kascontrol.core.hwcontrol import hwControl
from Code.kascontrol.core.hwc.hwmonitor import Monitor
from Code.kascontrol.core.network import Server
from Code.kascontrol.core.powermanager import PowerManager
from Code.kascontrol.electronics.drivers import pushbutton
from Code.kascontrol.globstuff import globstuff as gs
from Code.kascontrol.utils.errors import AbortInitError, ShutdownError


def run():
	logging.basicConfig(level=logging.DEBUG,
							  format="%(asctime)s - [%(levelname)s] - %(threadName)s - %(message)s",
							  datefmt="%m-%d %H:%M:%S",
							  filename=gs.logfile)

	try:
		# Initiating major modules:
		PowerManager()
		hwControl()
		Database()
		Server()
		# TODO: move buttons to json and init in hwinit
		# Adding buttons:
		if (gs.hwOptions["buttons"]):
			pushbutton.stopButton(gs.button0pin)
			# pushbutton.lightToggle(gs.button1pin)

		# Start recording the sensor data to the DB.
		datalog = DatalogThread(gs.getThreadNr(), "Datalog")
		gs.draadjes.append(datalog)
		datalog.start()

		# Start monitoring the soil and other sensors.
		monitor = Monitor(gs.getThreadNr(), "Monitor")
		gs.draadjes.append(monitor)
		monitor.start()

		gs.server.serverLoop()
	except AbortInitError:
		print("Something went wrong upon initalizing the server. See log for details.")
	except ShutdownError:
		logging.info("Shutdown by client.")
	except KeyboardInterrupt:
		logging.debug("Shutdown by keyboard.")
	finally:
		gs.shutdown()

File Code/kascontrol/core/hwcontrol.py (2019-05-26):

#!/usr/bin/python3

# Author: J. Saarloos
# v0.10.07	25-04-2019


from abc import ABCMeta, abstractmethod
import logging
import time

from ..globstuff import globstuff as gs
from ..utils.threadingutils import ProtoThread
from .hwc.dbchecks import DBchecks as dbc
from .hwc.faninterface import FanInterface as fni
from .hwc.floatswitchinterface import FloatSwitchInterface as fsi
from .hwc.hwgroups import HWgroups as hwg
from .hwc.hwinit import HWinit as ini
from .hwc.hwmonitor import HWmonitor as hwm
from .hwc.hwspoof import HWspoof as hws
from .hwc.powercontrollerinterface import PowerControllerInterface as pci
from .hwc.powerledinterface import PowerLEDinterface as pli
from .hwc.requestdata import RequestData as rqd
from .hwc.waterflowsensorinterface import WaterFlowSensorInterface as wfi
# from .hwc.hwinit import HWinit as ini


class hwControl(wfi, rqd, pli, pci, hws, hwm, hwg, fsi, fni, dbc, ini):
	"""
	Main object for interacting with the hardware and taking appropriate actions
	like watering, and making sensordata available to outputs (console/network/display/ledbar).
	"""

	__metaclass__ = ABCMeta

	def __init__(self):
		super(hwControl, self).__init__()
		gs.control = self


	def requestPumping(self, name, forTime = None):
		"""
		Method to request pumping water to a container. Requests will be accepted if
		enough resources are available, else it will be entered into a queue.
		"""

		check = False
		# Loop to wait while resources become available.
		while (not check):
			if (not self.__pump.isPumping):
				check, msg = self._checkIfPumpIsAvailable(self.__groups[name].valve, self.__pump)
			else:
				check, msg = self._checkIfPumpIsAvailable(self.__groups[name].valve)
			logging.info(msg)
			if (not check):
				time.sleep(1)
			if (not gs.running):
				return
		self.__groups[name].valve.on()
		# Turning on pump if not already pumping.
		if (not self.__pump.isPumping):
			time.sleep(0.1)
			self.__pump.on()
		if (forTime is not None):
			for i in range(int(forTime)):
				time.sleep(1)
				if (not gs.running):
					break
			self.endPumpRequest(name)

	def endPumpRequest(self, group):
		"""Turn off watering container."""

		# Checking if any other containers are being watered.
		i = 0
		for g in self.__groups.values():
			if (g.valve.open):
				if (not self.__groups[group] is g):
					i += 1
		# No other containers are being watered, turning off pump.
		if (i == 0):
			self.__pump.off()
			time.sleep(0.1)
		self.valves[group].off()

	def _checkIfPumpIsAvailable(self, *cur):
		"""Use this to check if the pump is available for use."""

		# Add calendar function.
		if (not self.__pump.enabled):
			return(False, "Pump is currently disabled.")
		if (not self.requestPower(cur)):
			return(False, "Not enough power available.")
		if (self.__floatSwitch.getStatus() and gs.hwOptions["floatswitch"]):
			return("Not enough water in the container.")
		return(True, "All good.")

	def disable(self):

		self.__enabled = False
		while (self.__pump.isPumping):
			time.sleep(0.1)
		self.__pump.off()

	def lcdNames(self, names):

		self.LCD.names(names)

	def isPumpEnabled(self):
		"""Returns pump availability"""

		return(self.__pump.enabled)

	def getSensors(self):
		"""Data for setting up database."""

		return(self.__sensors)

	def setLEDbarMode(self, mode):

		for bar in self.__LEDbars.values():
			bar.setMode(mode)

	def getLEDbarConfig(self):

		data = []
		for name, bar in self.__LEDbars.items():
			data.append(name)
			data.append(bar.getConfig())

	def connCheckValue(self):
		"""Returns the value below which a soil moisture sensor is considered disconnected."""

		return(self.__connectedCheckValue)

	def shutdown(self):
		"""
		Reset and turn off all in- and outputs and ICs when
		shutting down the system.
		"""

		if (gs.hwOptions["lcd"]):
			self.LCD.disable()
		if (gs.hwOptions["ledbars"]):
			for bar in self.__LEDbars.values():
				bar.setMode("off")
		self.__statusLED.off()
		self.__pump.disable()
		# Turn off valve in each Group.
		for g in self.__groups.values():
			g.valve.off()
		# reset INA219 devices if option.
		if (gs.hwOptions["powermonitor"]):
			for ina in self.__ina.values():
				ina.reset()
		if (gs.hwOptions["status LED"]):
			self.__statusLED.disable()
		self.__spi.close()
		self.__gpio.cleanup()

	@abstractmethod
	def requestPower(self, *cur):
		return super().requestPower(cur)


class PowerManager(ProtoThread):
	def run(self):
		logging.info("Starting thread{0}: {1}".format(self.threadID, self.name))
		gs.control.startPowerManager()
		logging.info("Exiting thread{0}: {1}".format(self.threadID, self.name))

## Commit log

2017-07-28 Adding PCB files
    This version doesn't have SPI working yet, so no analog data.
    [kas_mam-B.Cu.gbr, kas_mam-B.Mask.gbr, kas_mam-B.SilkS.gbr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]
2018-01-05 RevC v 1.1
    Fis for PCB. Should work now.
    [kas_mam-B.Cu.gbr, kas_mam-B.Mask.gbr, kas_mam-B.SilkS.gbr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]
2018-01-06 v2017
    Software for the revC 1.1 version of the board. Not nearly all features are suppoerted.
    [valves.csv]
2018-01-09 v2018-01-08
    Code is still work in progress. Won't run.
    [kascontrol.py]
2018-01-10 Update 2018-01-09
    Still not working.
    [sensorSetup.csv]
2018-01-28 Update 2018-01-27
    Updated mcp23017 driver to also support mcp23008. Still need to test it.
    Some more work was done on the ina219 driver. Lots more to be done.
2018-01-30 Update 2018-01-29
    Mostly got the INA210 driver closer to a working state.
    [sensorSetup.csv]
2018-02-02 Update 2018-02-01
    [sensorSetup.csv]
2018-02-10 Update 2018-02-09
    - Added support for MCP3x04, 'cause.
    - Added preliminary and non-functional support for HD44780 and LEDbars. Lots of code to be changed in the last one.
    - Other small updates.
    [sensorSetup.csv]
2018-02-11 PSU rev A PCB
    First version of my 5v / 12v 4A PSU with powermonitoring and support for some powerLEDs
    [PSU-B.Cu.gbr, PSU-B.Mask.gbr, PSU-B.SilkS.gbr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]
2018-02-11 Update 2018-02-09
    Plenty of large and small improvements. Not much closer to a working version :p
    [sensorSetup.csv]
2018-02-12 Update 2018-02-11
    Mostly added code for powerLEDs.
    Added some code for toggleable fan.
    Some other small updates.
2018-02-16 Update 2018-02-15
    Just some more misc fixes and updates.
    [database.py, group.py, hwcontrol.py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]
2018-02-17 Update 2018-02-16
    Added some code for hte lEDbars.
2018-03-02 PSU PCB rev A final
    [PSU-B.Cu.gbr, PSU-B.Mask.gbr, PSU-B.SilkS.gbr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]
2018-03-02 Main Board rev D
    [kas_mam-B.Cu.gbr, kas_mam-B.Mask.gbr, kas_mam-B.SilkS.gbr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]
2018-03-03 Update 2018-03-02
    Some improvements, better integration of LEDbars and LCD.
    [sensorSetup.csv]
2018-03-04 Update 2018-03-03
    Moved netCommand.getTabs method to globstuff so it is available to all systems.
    Started on an improved power management system based on a priority queue.
2018-03-04 Small cosmetic update
    [kas_mam.kicad_pcb]
2018-03-05 Update 2018-03-04
    Monitor method now collects data in a dict instead of a simple list.
    Fixed MCP230xx driver.
    [globstuff.py, hwcontrol.py, mcp23017.py]
2018-03-11 Update 2018-03-10
    Wokring code for LCD and LEDbars
    Removed a bunch of old code.
    Planty of other small changes.
2018-03-13 README
    Updated readme file to reflect the implementation of the LCD and LEDbars.
2018-03-17 Update 2018-03-16
    Mostly style updates and simple fixes.
    [database.py, group.py, hwcontrol.py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]
2018-05-22 Update 2018-05-21
    Added powerManager.
    introduced UUIDs to the mcp320xx drivers for exclusive pin usage.
    Changed sensorSetup file to JSON.
    Lots of misc fixes and updates.
    [sensorSetup.csv]
2018-07-09 Update 2018-07-09
    Various changes
    [PSU.sch]
